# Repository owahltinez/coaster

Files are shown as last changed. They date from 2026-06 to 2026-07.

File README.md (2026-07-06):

# Coaster

Very simple battery-operated device. When you push a button, the light turns on for a few seconds
and then it turns off. It is designed to be used as a coaster such that, when gently pushing a glass
down on the device, the light activates making the contents of the glass glow.

Pressing down on the coaster triggers a ~8 second light show: the LEDs ramp up to full
brightness, "breathe" gently five times, and fade back to black. Between shows the device
sleeps at ~1 µA — there is no on/off switch and none is needed.

## Repository layout

- `firmware/` — AVR C firmware and its build/flash Makefile.
- `pcb/` — v0.3 board design (KiCad, generated from python scripts) and footprints.
- `enclosure/` — 3D-printed shell (FreeCAD source + STEP/STL export).
- `tools/` — pinned toolchain containers (KiCad for the board, avr-gcc for the firmware).

All subdirectories share the same verbs, and the top-level Makefile forwards to each:
`make build` (firmware hex + board + enclosure exports), `make test` (flash-fit check +
board DRC + enclosure solidity check), `make clean`. Domain-specific verbs forward to the
relevant subdirectory: `make flash` / `make fuses` (firmware programming),
`make review` (board render / PDF / STEP), `make fab` (JLCPCB order bundle). The
firmware and PCB verbs run inside pinned containers — `make image` builds them once
(see Software); flashing stays on the host.

## How it works

The button connects an MCU pin (with its internal pull-up) to ground. Pressing it fires a
falling-edge interrupt on one of the ATtiny202's fully-asynchronous pins, which wakes the
chip from power-down sleep with the main clock stopped — a press costs effectively no
charge. The firmware debounces the edge, plays the show over hardware PWM through a
MOSFET driving four series-resistored LEDs, and goes back to sleep.

Two details carry hard-won lessons from v0.2:

- The show also plays once when the battery is inserted (a power-on reset doubles as a
  built-in self test), but *only* on a power-on reset: a brown-out reset means a dying
  cell sagged below 1.8V mid-show, and playing again would loop the cell to death — so a
  brown-out goes straight back to sleep and the coaster simply dims gracefully as the
  battery wears out.
- Wake edges that turn out not to be presses (e.g. contact bounce while lifting a glass
  off a held-down button) are filtered by a 20ms debounce check, so the show plays on
  deliberate presses only.

## Hardware

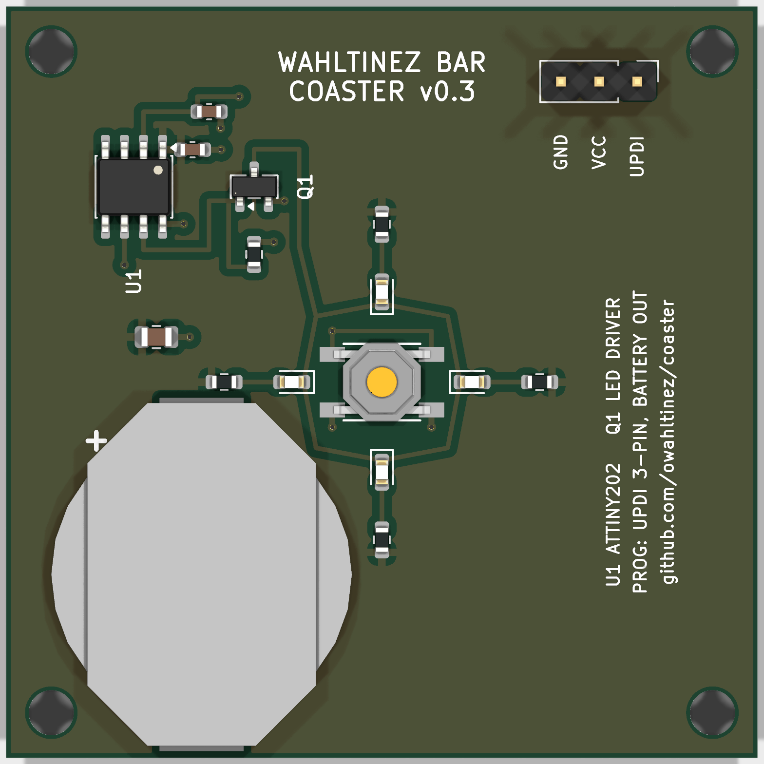
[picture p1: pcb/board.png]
coaster v0.3 board


The v0.3 design (KiCad) lives in `pcb/`:

- `pcb/design.py` is the circuit as data — parts, placements, and the netlist defined
  once. This is the file to read or edit; it is the source of truth.
- `pcb/DESIGN.md` is the design specification: pin map, BOM with part rationale,
  ordering plan, and the validation checklists.
- `pcb/generate.py` turns `design.py` into `coaster.kicad_pcb` (committed for
  convenience). `make build` regenerates the board and validates connectivity; `make
  test` runs DRC; `make review` produces a board render, a 1:1 printable PDF, and a STEP
  model for CAD fit checks.
- `pcb/coaster.pretty/` — project footprints with pad geometry extracted from the
  manufactured v0.2 board (battery holder, tactile switch).

There is no schematic: JLCPCB takes Gerbers + BOM + CPL (not a schematic), the board is
built and checked directly against `design.py`, and `design.py` itself documents the
circuit — so a derived schematic would add nothing.

The previous revision (v0.2: ATtiny13A, EasyEDA, CR2032) is archived at release
[v0.2.1](https://github.com/owahltinez/coaster/releases/tag/v0.2.1), including its
firmware, schematic renderings, and 3D printing assets.

### Production

All SMD parts are LCSC-stocked, so the board can be fabricated and assembled through
JLCPCB — the only hand-assembly per unit is dropping a CR2016 into the holder. `make
fab` writes the three JLCPCB uploads (Gerbers zip + BOM + CPL) to `pcb/dist/`; order
with **white soldermask** (the board face is the reflector behind the LEDs). The full
step-by-step — orientation checks, stock confirmation, post-assembly flashing — is the
ordering plan in [pcb/DESIGN.md](pcb/DESIGN.md).

Rough per-unit estimates as of June 2026 (USD, assembled and shipped; ~A$1.55/US$):

| Per unit | Qty 30  | Qty 100 | Qty 1k  | Qty 10k |
|---|---|---|---|---|
| Parts | $0.74 | $0.70 | ~$0.60  | ~$0.47  |
| Feeder/setup/stencil | $0.72 | $0.30 | ~$0.04  | ~$0 |
| PCB + assembly | $0.47 | $0.40 | ~$0.30  | ~$0.20  |
| Board shipping | $0.20 | $0.35 | ~$0.10  | ~$0.05  |
| CR2016 (name-brand) | $0.65 | $0.35 | ~$0.20  | ~$0.12  |
| Enclosure | $0.60 (FDM) | $0.60 (FDM) | ~$1.00 (print farm)\* | ~$0.30 (molded)\* |
| **Finished coaster** | **~$3.40** | **~$2.70** | **~$2.25** | **~$1.10** |

\*The 1k column keeps FDM but prices it honestly: ~2,500 printer-hours, which a small
farm of four budget printers clears in under a month — filament plus printer
amortization lands near $1/unit, with no tooling commitment and the printers kept at
the end. The 10k column switches to injection molding (aluminum tooling, amortized);
that is also the column where a further redesign pays — shrinking the PCB from the
structural 50×50mm to a ~25mm puck and letting the molded shell carry the mechanical
roles would cut the PCB line by ~$0.10 more. If 1k is a milestone toward 10k rather
than the destination, rapid aluminum tooling (~$1–1.5k) prices similarly at 1k and
carries forward.

The electronics architecture is the same in every column — the MCU ($0.30–0.43) is the
cheapest line that matters, and it is the entire personality of the product. Prices
drift; get a real quote from the [JLCPCB quote tool](https://jlcpcb.com/quote) and
confirm ATtiny202 stock at order time (the ATtiny402 is a firmware-compatible drop-in
substitute).

## Software

The firmware and board builds run in **pinned containers** (`tools/`), so the host
needs neither a KiCad nor an AVR toolchain — only a container engine. Pinning is what
keeps the artifacts reproducible: the committed board is KiCad-10 format and host KiCad
drifts (Debian ships v9, which can't even open a v10 board), and the ATtiny202 firmware
needs avr-gcc ≥ 12 (the README used to hand-source `avr-gcc@14` from the
[osx-cross/avr](https://github.com/osx-cross/homebrew-avr) tap on macOS). Build the
images once, then the verbs route through them automatically:

```bash
make image               # build both images: coaster-fw + coaster-pcb (re-run after editing a Containerfile)
make build               # firmware hex + board + enclosure, each in its toolchain
make fab                 # regenerate the board + emit the JLCPCB bundle, in the container
```

The enclosure builds the same way, in a pinned FreeCAD 1.1.1 container (`make image`
builds it too) — so the host needs no FreeCAD either, and the old macOS `freecadcmd`
symlink dance is gone.

`docker` here is a [Podman](https://podman.io) alias (`podman-docker`); override
`CONTAINER_ENGINE` to use another runtime. Rootless Podman maps container-root to your
UID (the Makefile passes `--user 0`), so generated files come back owned by you. The
rule is **produce artifacts in a container, touch hardware on the host** — so flashing
(`make flash` / `make fuses`, which need a USB-serial adapter) stays on the host and
needs `avrdude` (≥ 7, for `serialupdi`) installed there; see Flashing below.

The **enclosure** build still runs on the host via FreeCAD (`freecadcmd`); on macOS the
app bundle doesn't expose its CLI, so symlink it once:

```bash
ln -s /Applications/FreeCAD.app/Contents/Resources/bin/freecadcmd /opt/homebrew/bin/freecadcmd
```

### Flashing

No dedicated programmer needed: UPDI works over any USB-serial adapter with a single
~1kΩ resistor bridging the adapter's TX to RX, and RX wired to the board's UPDI pad
(plus VDD and GND — the J1 pads are labeled on the silkscreen).

```bash
make flash   # writes main.hex over serialupdi
make fuses   # once per chip: brown-out detector at 1.8V, sampled in sleep
```

The fuses matter: the factory default leaves the BOD disabled, which allows undefined
behavior when the battery sags, and the firmware's brown-out logic depends on it.

For flashing a stack of boards hands-free, `make flash-loop` runs a continuous loop:
plug a board onto the jig, it flashes + fuses + verifies automatically, then waits for
you to remove it before arming the next. **The board reports its own result** — a good
flash plays a distinct rapid blink and a failed one stays dark, so you never look at the
screen. The blink is gated on a one-shot EEPROM flag the loop writes only after both
flash and fuses verify (a single avrdude run, which aborts before the arm step on any
earlier failure); the firmware blinks once on the next boot and clears the flag, so it
fires exactly once per flash and never again in the field.

Gotchas:

- **Remove the coin cell before flashing.** The adapter drives VDD and would back-feed
  the (non-rechargeable) lithium cell.
- That's it. The v0.2 list of ISP gotchas (LEDs clamping MOSI, flaky readback, wedged
  programmers) died with the ISP header: UPDI shares no pins with anything else on this
  board, by construction.

## Power estimates

Assumptions: CR2016 rated at 75 mAh (~70 mAh usable), ~8 mA LED draw at 100% duty on a
fresh cell, ~1 µA sleep current (BOD sampled).

| Event | Cost | Notes |
|---|---|---|
| Light show (~8 s) | ~15 µAh  | avg ~60% LED duty + ~1.5 mA MCU active |
| Button press | ~0 | pin-change wake; nothing touches the supply |
| Standby (per day) | ~26 µAh  | ~1 µA sleep + battery self-discharge |

Expected battery life:

| Usage pattern | Battery life |
|---|---|
| Never pressed (shelf) | ~7 years |
| ~5 presses/day | ~2 years |
| ~30 presses/day (bar duty)  | ~5 months |
| Theoretical max shows | ~4,500 |

The punchline: v0.3 runs on a cell with a third of the v0.2 battery's capacity and
still matches its life, because presses are now free (each v0.2 press dead-shorted the
battery and cost as much as a show) and sleep current dropped ~4×.

## Demo

> TODO: Add demo pictures / video.

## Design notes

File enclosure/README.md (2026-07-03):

# Enclosure

3D-printed shell for the coaster. The top is a solid "donut-piston": a
continuous disc that holds the static weight of a glass but deflects as a whole
— piston-style, carried on a ring of snap arms — to click the tactile button at
the center of the PCB. (The v0.2 lid was a spiral flexure; v0.3 replaced it with
this solid piston.)

`coaster.FCStd` (FreeCAD) is the CAD source of truth. It contains two bodies,
each exported as its own print/CAD artifact:

| Body | Size (mm)  | What it is |
|---|---|---|
| Top | Ø90 x 5.4  | Solid donut-piston lid: skin + central press post + 6 snap arms |
| Bottom | Ø90 x 6.5  | Base tray holding the PCB |

Assembled height is **8.1 mm** (the lid nests into the tray). The tray wall is
the single height knob (`VarSet.BottomHeight`): the lid sits on the wall rim and
its placement, the snap-pocket depth, and the rim ceiling all track it, so
changing `BottomHeight` moves the whole interlock rigidly. The one feature that
does *not* track is the central `Press Post` (it grows down from the lid skin);
its length must change by the same amount in the opposite sense to keep the post
tip on the button — at `BottomHeight` 6.5 the post is 3.5 mm. (v0.3.0 shipped at
`BottomHeight` 7.5 / 9.1 mm tall; the tray was thinned 1.0 mm after the CR2016
holder replaced the CR2032.)

The tray floor under the board (the `PCB Recess` pocket floor) is **0.6 mm** — three full
print layers. It was 0.5 mm, an awkward 2.5 layers that printed thin and dimpled a little when
the board was pressed onto the pegs. The board sits flat *on* this floor, so it can't be
thickened much without cost: more material either raises the board into the tight lid/holder
clearance or makes the coaster taller (the underside is flat on the table — no dead space). So
the fix is minimal: make `PCB Recess` 0.1 mm shallower (1.5 → 1.4 mm), raising the whole indent
floor uniformly to 0.6 mm. The board seat rises 0.1 mm (negligible for post travel) and overall
height is unchanged.

**This 1.0 mm is on probation — confirm it on a printed article before a batch.**
The constraint is not static fit but press deflection: the donut-piston deflects
~0.6 mm down at the battery-holder radius under a heavy glass press, and at a
6.5 mm tray it has only ~0.25 mm of static clearance over the holder there. So
the lid is expected to *graze* the holder under the heaviest glasses — which
stiffens the press rather than blocking the click (the holder adds a support, it
does not lock the centre post). An axisymmetric sim can't settle how much this
changes the feel; print one tray, drop in a populated board, and press a real
glass. If the press feels notably stiffer or the holder shows witness marks,
back `BottomHeight` off toward 7.0 (each 0.1 mm buys ~0.1 mm of clearance).

## Building

The build runs in a pinned FreeCAD 1.1.1 container (`tools/Containerfile.cad`), so the
host needs no FreeCAD — `make image` (from the repo root) builds it once. The source is
authored in FreeCAD 1.1; stable 1.0.0 breaks the sketch/Origin attachment, so the
version is pinned to match. Same verbs as the other subdirectories (run from the repo
root so they route through the container, or `make -C enclosure …` inside it):

```bash
make build   # validate + export coaster-{top,bottom}.{step,stl}
make test    # validate only: full recompute, every body a valid closed solid
make clean
```

The STL files are the 3D printing assets; the STEP files are for CAD
interference checks against the board (`make -C ../pcb review` exports the
matching `coaster.step` board model).

Material use (solid volume from the model × 1.24 g/cm³ PLA; the bodies are
thin-walled, so a real print lands close): Top 8.3 cm³ (~10 g), Bottom 11.4 cm³
(~14 g) — about 24 g and ~$0.50 of filament per coaster. Re-slice to confirm.

## Liquid strategy

The coaster lives under sweating glasses. The v0.2 lid was a spiral flexure whose cuts
were an open path into the shell, plugged by a separate clear-PETG shield membrane. The
v0.3 donut-piston removes the problem instead of patching it: the top is a **continuous
solid skin with no through-cuts**, so drips and condensation that reach it shed outward and
never find a path to the electronics, the bare battery contact, or the switch. The lid is
its own barrier — which is why v0.3 has no Shield body.

**Anti-stick — flat v0.3, radial ridges in v0.3.1.** A bare smooth skin has a second liquid
problem: a sweat film between a glass base and the flat top is a capillary bond — order ~N of
pull, against the coaster's own ~0.24 N weight — that lifts the whole lightweight coaster when
the glass is raised. **v0.3** ships the plain flat lid (`coaster-v0.3.FCStd`); the anti-stick
texture is **v0.3.1** (`coaster.FCStd`, the live source).

A shallow *recessed field* between raised dots (an earlier printed attempt) makes it **worse**:
sweat floods the 0.4 mm field, bridges into one continuous film, and the whole thing becomes a
suction cup. The lesson from that print: the fix is **drainage**, not contact-area reduction.
v0.3.1 cuts **12 radial channels** (2.0 mm wide × 0.8 mm deep) running from r≈13 to r≈42. They
*drain* sweat off toward the edge and give air a straight path in the instant the glass lifts —
no standing film to seal. (A first print with 24 thin 1.0 × 0.4 mm lines was wrong: the lines
were too small to feel and fused, and running them to the very rim printed jagged. Fewer, much
wider and deeper channels that stop ~3 mm short of the edge print cleanly and are actually
felt.) The channel walls are **tapered ~40°** from vertical (`TaperAngle` on the pocket) — wide
at the glass face, narrowing to a ~0.8 mm floor. Since the Top prints face-down, the channel is
a recess in the bed-side surface; a square `]` profile would leave a flat, down-facing floor
that bridges and prints rough, whereas the taper makes the walls self-supporting overhangs and
shrinks that bridge. (A self-supporting *full* V — no flat floor — needs width ≤ 2× depth, i.e.
~1.6 mm at this 0.8 mm depth; 2.0 mm/40° is the chosen middle ground between width and a small
floor.) It also drains better — no square corners to trap water. Radial (not a grid or field)
also prints well: the rim between channels stays flat, and the flat r42–45 band gives the
face-down print a clean, continuous first-layer perimeter.

The channels are **blind**: floors leave ≥ 0.8 mm of skin in the disc, so the waterproof barrier
holds; plateaus between them are full thickness. The channel depth is **uniform 0.8 mm the whole
way** — including across the 0.4 mm outer flexure hinge, where a full-depth groove would otherwise
breach. Rather than shallowing the groove there (which left an ugly depth step), the fix adds
material on the *underside* directly beneath each channel at the hinge: **12 discrete backing bars**
(3.5 mm wide × 1.2 mm) so 0.4 mm of skin remains under the 0.8 mm groove. Because the channels are
radial, the bars don't island the thin membrane, and the hinge still flexes *between* them, so the
click stays near the flat lid's (the bars are non-axisymmetric, so `sim/` slices between them and
can't score their small stiffening; see `meridian_polygon`). The inner hinge and the central
button/LED zone are left ungrooved. Earlier forms — a spider-web, a square grid, a bump field —
were busier, off-centre on the round face, or (the bump field) actively worse in a print; simple
uniform-depth radial drainage channels are the result.

## Press mechanics

The donut-piston's click force and travel are simulated in `sim/` — an axisymmetric FEA
of the Top sliced straight from this `coaster.FCStd` and calibrated to a measured press.
See `sim/README.md`.

## Snap arms (known weak point)

The six cantilever arms latch the lid into the tray pockets, and they are the enclosure's
fragility hotspot. The flexing beam is short (~1.5 mm), so even the ~0.25 mm it deflects
to clear the wall lip on insertion is a high bending strain at the root — the arms crack
there. Levers, in order of effect:

- **Beam thickness** (`Sketch004` datum 16, the radial dimension) — set to **1.6 mm**, the
  thickest the root fillets allow with the hook at mid-beam (1.8 mm+ makes the fillets fail
  to resolve). Two effects trade off: thicker prints more robustly with better layer bonding
  (a thin ~1.0 mm arm prints as a fragile near-single-wall column), but thicker also raises
  the bending strain on the ~0.25 mm snap-over. Which dominates is a print-test question.
  That thick + fillet fight for room at the root is the argument for eventually moving the
  hook to the tip — it frees the root for a thick, well-filleted, long-flexing beam.
- **Material** — print in **PETG** (ductile; the press sim assumes it). PLA snaps.
- **Orientation** — the arms bend radially, so on a flat-printed lid the layer lines run
  *across* the bending plane and the root fails by delamination regardless of strain. There
  is no single orientation that favours all six radial arms; print with extra perimeters so
  the beam is near-solid, and treat orientation as a likely co-cause if cracking persists.
- **Root fillets** — outer (tension-side) and inner both 0.8 mm; relieve the stress
  concentration only, not the bulk strain.

If thinning + PETG + perimeters still isn't enough, the cantilever is at the limit of what
this footprint allows and the retention method itself should be reconsidered.

Lateral fit between lid and tray is set entirely by the arms in their pockets — the lid
just rests on the wall rim, there is no separate register. The tangential fit is
`Pocket002.Length` minus the arm width `Pad003.Length` (4.0 mm), and it is a per-printer
tuning knob: the model is line-to-line radially and the pocket runs 0.1 mm wider than the
arm tangentially (`Pocket002.Length` = 4.1), so most felt play is print tolerance opening
the fit. Tighten `Pocket002.Length` toward 4.0 if the lid wobbles; loosen it if the lid
binds going on.

## Design constraints (50 x 50 mm board)

- Board outline: 50 x 50 mm, 3 mm mounting holes in all four corners at
  (3, 3), (3, 47), (47, 3), (47, 47).
- The piston must press the button at the board center.
- Center clearance: the LED ring sits 6 mm from center; the central press post
  must stay narrow enough not to cover the LEDs.
- The UPDI programming header (J1, near a board-edge corner) must stay reachable,
  or accept opening the shell to reflash.

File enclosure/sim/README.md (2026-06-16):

# Press-mechanics simulation

Predicts the coaster's **click force** — how hard you must press, and where, to
actuate the center switch — directly from the CAD. Run it after changing the
Top to check the press feel before committing a print.

```bash
make sim                 # from the repo root: runs in the pinned container
make -C enclosure sim     # on the host (needs FreeCAD with bundled gmsh + ccx)
```

Outputs (regenerated each run, git-ignored): `results.md` (the report) and
`curve.svg` (the headline plot — click force vs. load radius).

---

## The method (reusable for any solid-of-revolution part)

This harness is a worked example of a general technique: **calibrated
axisymmetric FEA driven straight off the CAD solid.** The ideas below transfer
to any revolved mechanism (a snap dome, a diaphragm, a Belleville spring, a
press-fit boss).

### 1. Slice the real solid — don't reconstruct it

The Top is a solid of revolution, so its press mechanics reduce *exactly* to a
2D axisymmetric problem. Instead of re-authoring the shape as code (which then
drifts from the CAD), `model.meridian_polygon` **cuts the real FreeCAD solid**
through an arm-free axial plane and returns the `(r, z)` meridian outline. Gmsh
meshes that polygon into quadratic axisymmetric triangles (CAX6); CalculiX
solves a linear static load. Because the mesh *is* the sliced section, the
simulation can never disagree with the model — change the donut, the hinge, the
post, re-run, and the section follows. It also handles whatever the shape
becomes (corrugations, fillets) with no code change.

The snap arms break strict axisymmetry but carry no press load, so the slicer
sweeps azimuths to find a plane that misses them.

### 2. Why 2D, not the "real" 3D solid

A full 3D solve of the *actual* solid is the obvious thing to want, and it's the
wrong tool here. The press response is dominated by bending of the 0.4 mm
membrane/hinge, which needs ~3 elements through its thickness. In a 2D
axisymmetric slice that is free (~10k elements, sub-second). In 3D it forces
~0.13 mm elements across a 90 mm disk — millions of tetrahedra, minutes to mesh,
many minutes to hours to solve, and finicky to even mesh cleanly (we measured
this). Axisymmetry is the correct, cheap, *more accurate* tool for a revolved
part. 3D only earns its cost for genuinely non-axisymmetric questions (e.g. how
much an off-center glass *tilts*), which this design doesn't hinge on.

### 3. Calibrate the scale from one measured press

The model is linear, so the absolute modulus only sets an overall compliance
scale — it cancels. We fix that scale with **one measured click force**: press
the printed part at a known spot, read the grams at the click (`CALIBRATION`).
Everything else then follows from FE compliance *ratios*, which need no
material constant. (`E_MPA`, `MESH_SIZE` are solver settings, not design data.)

### 4. Validate with a second press at a different radius

With two measured presses at different radii, the model must reproduce their
**click-force ratio from geometry alone** — a real falsifiable check, not a fit.
Here the center press (330 g) and a two-finger press on the donut (1400 g) give
a 4.24× ratio; the model predicts it within ~10% and the two presses agree on
the absolute scale to ~10%. The residual is the center press's sensitivity to
how a fingertip's pressure distributes; the two-finger press (a clean ring) is
the robust scale anchor.

### 5. The output is a curve, because contact location is everything

A glass is a tube: the press force runs **down its walls** and enters the base
as a *ring at the wall radius* — not spread over the base, not at the base rim.
So the meaningful input is the **load radius**, and the output is a click-force-
vs-load-radius curve (`curve.svg`). To predict a glass, read the curve at its
load radius:

- **Recessed base** → loads on its recess ring (clean; the model nails it).
- **Flat base** → loads a few mm *inboard* of its contact edge (the surface
  dishes away from the rim under load), so use ~edge radius minus a few mm.

### 6. Don't model the presser — and know the limits

Modeling the glass as a body (contact analysis) was tried and isn't worth it:
its entire effect reduces to "a ring at the load radius," while a contact solve
adds fragile unilateral-contact nonlinearity and per-glass geometry — and it
would *not* remove the residual uncertainty, because that's set by sub-mm base
flatness. Honest accuracy budget: **point/finger presses and the curve *shape*
are reliable; flat-glass absolute force carries ~±1 kg** from contact detail.
That's fine for "comfortable and won't self-trigger," not a precision number.

---

## Files

- `model.py` — the model as data + functions: the calibration presses and
  validation glasses (the only inputs the CAD lacks), and the slice → mesh →
  solve → parse machinery. Geometry is read from the FCStd, never typed here.
- `run.py` — orchestration: slice + mesh once, solve the presses (scale +
  validation) and the radius sweep, write `results.md` and `curve.svg`.
- `gmsh` and `ccx` ship inside the pinned FreeCAD container, so `make sim`
  needs no extra tools; `model.locate` also finds them in a host FreeCAD.

## Reusing this on another part

1. Point `model.DESIGN_FILE` at the new FCStd; make sure the bodies/sketches the
   model reads by label (`Wall Profile` for the seat radius, etc.) exist or
   adjust `read_design`.
2. Print it, measure one click force to set `CALIBRATION`, and ideally a second
   at a different radius to validate.
3. `make sim`.

## Note on the design file

This models `enclosure/coaster.FCStd` — the donut-piston Top that `export.py`
builds and the canonical enclosure for v0.3. (The v0.2 spiral flexure it
replaced lives at tag v0.2.1.)

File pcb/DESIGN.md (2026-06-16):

# Coaster v0.3 — Design Specification

The circuit itself lives in `design.py` (the single source of truth); this document
records the design intent: how the MCU is wired, why each part is what it is, and what
to verify before committing to a batch. The previous revision (v0.2: ATtiny13A,
EasyEDA) is archived at release v0.2.1; every choice below traces to a lesson learned
debugging it.

## Design rationale

- **MCU: ATtiny202** — in production, real brown-out detector, UPDI single-wire
  programming, ~1µA power-down sleep. 2KB flash / 128B SRAM is 7× the current
  firmware; the ATtiny402 (4KB/256B) is a drop-in substitute at +$0.22 if the
  firmware ever outgrows it — a binary built for the 202 runs unmodified on a 402.
- **Button on a GPIO with pin-interrupt wake** — presses cost ~0 µAh and richer UX
  (double-tap, long-press) becomes possible. v0.2 woke by dead-shorting the battery,
  which cost ~11 µAh per press and destroyed SRAM state.
- **One series resistor per LED + low-side MOSFET driver** — LED current set by
  design, not by battery internal resistance and pin-driver luck.
- **Real decoupling (C1) and bulk (C2) capacitance** — transient immunity; rides
  through battery-holder micro-dropouts.
- **3-pad UPDI header** — programming cannot collide with the LEDs by construction
  (v0.2's ISP shared the LED pin, which made flashing finicky).

## MCU pin map (ATtiny202, SOIC-8)

| Pin | Port | Net | Function |
|-----|---|---|---|
| 1 | VDD  | VCC | Power |
| 2 | PA6  | BUTTON | Button input, internal pull-up, falling-edge wake. PA6 chosen deliberately: Px2/Px6 are the fully-asynchronous pins that can edge-wake from power-down |
| 3 | PA7  | — | Unused (firmware enables pull-up) |
| 4 | PA1  | — | Unused / spare test pad (optional) |
| 5 | PA2  | — | Unused / spare test pad (optional) |
| 6 | PA0  | UPDI | Programming only — route to header, leave in UPDI mode (do NOT fuse to GPIO/RESET) |
| 7 | PA3  | LED_PWM  | TCA0 WO0 hardware PWM → MOSFET gate |
| 8 | GND  | GND | Ground |

## Connections (net by net)

```
VCC:      BT1+, U1-1, C1-1, C2-1, R1-1, R2-1, R3-1, R4-1, J1-2 (UPDI header VDD)
GND:      BT1-, U1-8, C1-2, C2-2, Q1-source, SW1-(2nd terminal), C3-2, R5-2, J1-3
LED_PWM:  U1-7 (PA3), Q1-gate, R5-1 (100k pulldown to GND)
LED_K:    Q1-drain, L1-cathode, L2-cathode, L3-cathode, L4-cathode
LED legs: VCC → R{1..4} (100Ω) → L{1..4} anode ; all cathodes → LED_K
BUTTON:   U1-2 (PA6), SW1-(1st terminal), C3-1 (100nF debounce, optional)
UPDI:     U1-6 (PA0), J1-1
```

Notes:

- R5 (gate pulldown) keeps the LEDs off while PA3 floats during programming/reset.
- C1 must sit physically adjacent to U1 pins 1/8; C2 anywhere near the battery holder.
- 100Ω per LED ≈ 3–5mA per LED fresh (3.2V → Vf 2.7V across 100Ω), tapering toward ~0
  as the cell sags to Vf; total LED load ~12–20mA fresh. Through the MOSFET, the MCU pin
  only drives gate charge. (The resistor is more ballast than limiter at this headroom —
  matches the four parallel LEDs; first-article measurement sets the final value.)
- J1: 1×3 through-hole pads, 2.54mm pitch, near the board edge: [UPDI | VDD | GND].
  Through-hole so a header can be pressed in at an angle or soldered for batch work.

## BOM (with JLCPCB catalog tier)

| Ref | Part | Package | LCSC # | Tier | ~Unit USD |
|-----|---|---|---|---|---|
| U1 | ATtiny202-SSN | SOIC-8 | C2052951 (-SSNR) | Extended | 0.43 |
| Q1 | AO3400A N-MOSFET | SOT-23 | C20917 | Basic | 0.01 |
| L1–L4 | White LED KT-0603W | 0603 | C2290 | Basic | 0.003 |
| R1–R4 | 100Ω 1% | 0603 | C22775 | Basic | 0.001 |
| R5 | 100kΩ 1% | 0603 | C25803 | Basic | 0.001 |
| C1 | 100nF X7R 50V | 0603 | C14663 | Basic | 0.001 |
| C2 | 22µF X5R 25V | 0805 | C45783 | Basic | 0.01 |
| C3 | 100nF (debounce, optional) | 0603 | C14663 | Basic | 0.001 |
| SW1 | Tactile switch TS-1187A-B-A-B | SMD | C318884 | Extended | 0.02 |
| BT1 | CR2016 holder MY-2016-02 | SMD | C2979176 | Extended | 0.16 |

These LCSC numbers are the source of truth in `design.py`'s `LCSC` map, from
which `make fab` emits the BOM — the table here is documentation. The five
non-jellybean parts are deliberate (see below); the passives are pinned to
in-stock JLCPCB *Basic* SKUs (no feeder fee), substitutable by any same
value/package/tolerance Basic part if one lapses. Per-board parts ≈ $0.74 USD. Extended parts (U1, SW1, BT1) cost a $3 feeder fee
each per order — $0.30/board at qty 30. Option: leave BT1 off the assembly and
hand-solder it (two large pads) to save its fee.

Part choices worth defending:

- **Q1 must be a logic-level FET.** The AO3400A (Vgs(th) 0.65–1.45V) is fully enhanced
  at worn-cell voltage; a 2N7002 (Vgs(th) up to 2.5V worst-case) would be driven barely
  above threshold for most of the cell's life and read as dim/flickering LEDs.
- **L1–L4: efficiency at coin-cell current, not headline mcd.** Every white LED is
  ~2.7–3.4V Vf (blue die + phosphor), and a CR2016 offers only ~0.3V above Vf — so the
  LEDs run at a few mA, never their 20mA rating, and the figure that matters is light
  per mA at low current, not mcd@20mA. The KT-0603W (Basic, C2290) gives 360mcd @ 5mA
  (~72 mcd/mA) versus the XL-1608UWC-04's 130mcd @ 20mA (~6.5 mcd/mA): ~11× the light at
  the current this circuit actually delivers — and it's a Basic part, so no feeder fee.
  The glow is the entire point of the device; this is where it's bought. (An earlier
  revision had this backwards and paid a feeder fee for the dimmer part — see git log.)
- **SW1 is mechanically load-bearing.** The enclosure flexure is dimensioned around
  this switch's body height and actuation force, and its footprint is the one extracted
  from the manufactured v0.2 board. A basic-catalog switch would save $0.10/board and
  risk re-validating the press feel.
- **BT1 takes a CR2016, not a CR2032.** Same Ø20mm cell, but the MY-2016-02 holder is
  2.2mm tall versus 3.6mm, slimming the enclosure (the holder was the tallest
  component). ~75mAh still gives 2+ years at a few presses a day — µA sleep dominates
  and presses are now ~free.

## Ordering plan

30 boards, JLCPCB Economic assembly (30 is the Economic cap — the per-unit sweet spot).
Estimated ~$100–105 AUD shipped (economy mail).

`make fab` generates the three JLCPCB uploads into `pcb/dist/` (gitignored) from the
board geometry and `design.py`'s part data: `coaster-gerbers.zip` (Gerbers + drill),
`coaster-bom.csv`, and `coaster-cpl.csv` (pick-and-place). The UPDI header (J1,
through-hole) and the mounting holes are excluded from assembly — J1 is pressed/soldered
by hand for batch flashing. Then at the JLCPCB quote tool:

1. Upload `coaster-gerbers.zip`; set **white soldermask** (same price): the board face
   is the reflector behind the LEDs — dark mask absorbs a large fraction of the show's
   light for free.
2. Quantity 30, SMT assembly on the top side; upload `coaster-bom.csv` and
   `coaster-cpl.csv`.
3. Confirm **ATtiny202 (C2052951)** stock/tier at order time; if out of stock, the
   ATtiny402 is a drop-in substitute (same firmware binary), or order assembly without U1
   and hand-solder the SOIC-8s.
4. On the assembly preview, **verify part orientations**. The KiCad and JLCPCB rotation
   conventions differ for some packages, and `ROTATION_CORRECTION` in `design.py` is empty
   until a real preview is checked. The one that bites: BT1's pads are symmetric but the
   part is not — the insertion mouth must face the **west** board edge (cell slides in/out
   over bare board). Record any rotation fix in `ROTATION_CORRECTION` (keyed by footprint)
   and re-run `make fab`, so the next order is right by construction.

Boards arrive **blank**: program each over the UPDI header (`make fuses` once to set the
1.8V BOD, then `make flash`) and drop in a CR2016 — the cells are not part of the JLCPCB
order. Validate one unit against the first-article checklist below before committing the
batch to enclosures and cells.

## Firmware port checklist (ATtiny13A → ATtiny202)

- [x] PWM: TCA0 in single-slope PWM, WO0 on PA3 (default PORTMUX routing); duty updates
      via CMP0BUF; bright phase at full duty now that R1–R4 set the current
- [x] Button: PA6 input, internal pull-up (PORTA.PIN6CTRL), falling-edge interrupt, wake from power-down
- [x] Sleep: SLPCTRL power-down; expected sleep current ~0.1–2µA (BOD in sampled mode)
- [x] BOD: configured via FUSE.BODCFG at programming time (`make fuses`, 0x06) — enabled
      at 1.8V, sampled mode in sleep
- [x] Debounce in firmware (20ms, also filters release-bounce edges); C3 is belt-and-suspenders
- [x] Show logic carries over: ramp, breathe ×5 ending on the dim phase, squared perceptual
      fade (~8s total; the v0.2 battery-recovery settle phase is gone — presses no longer
      touch the supply rail)
- [x] Reset logic: show on `PORF` only (battery insertion = self-test); a brown-out reset
      skips to sleep so a dying cell cannot reset-relight; button wakes are not resets at all
- [x] Programming: avrdude serialupdi (any USB-serial adapter + 1 resistor), `make flash`

Builds at 422 / 2048 bytes with avr-gcc 14. Hardware verification of all of the above
lives in the first-article checklist below.

## First-article validation (before deploying all 30)

- [ ] Programming via UPDI header works
- [ ] Sleep current measured < 5µA
- [ ] Show plays on button press; press costs no measurable charge
- [ ] Brightness through an actual glass: 100Ω is a starting value, not a decision —
      if too dim, rework toward 68Ω and re-measure worn-battery behavior; if it drains
      too fast, back off toward 150Ω
- [ ] LED polarity on the assembly preview: cathode (pad 1) faces the board center
      (LED_K). The KT-0603W is a new part vs the preview-checked rc1 LED — confirm its
      orientation; if reversed, add the LED footprint to ROTATION_CORRECTION (+180) and
      re-run `make fab` (CPL only; gerbers unchanged)
- [ ] Worn-battery test: show degrades gracefully (dims) with no reset loop
- [ ] Bench-supply + series-resistor test (30–50Ω) simulating a dying cell
- [ ] Press during show, long-press, rapid double-press behave sanely
- [ ] Splash test: assembled unit, dribble water over the top — the solid piston lid
      sheds it, nothing reaches the PCB, battery contact stays dry, button still clicks

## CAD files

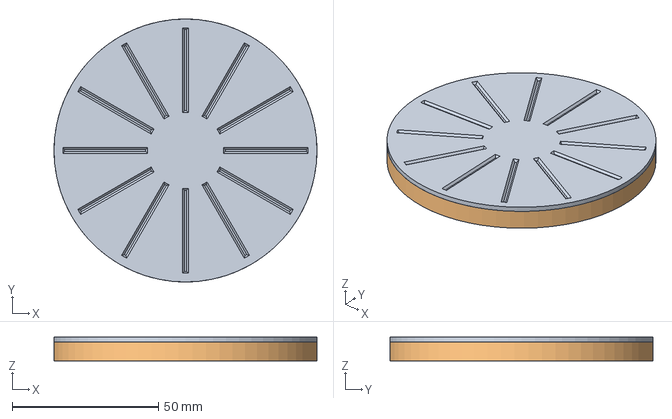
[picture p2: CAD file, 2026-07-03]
enclosure/coaster.FCStd
90.0 x 90.0 x 8.10 mm
Top
Bottom

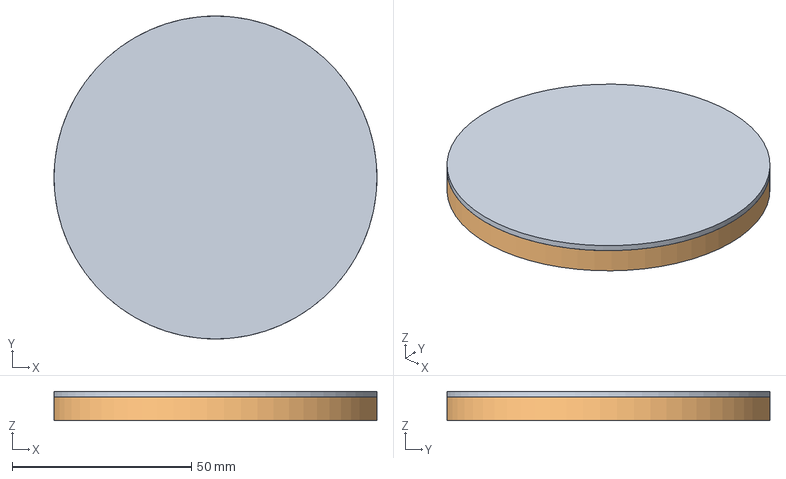
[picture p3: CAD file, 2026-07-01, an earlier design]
enclosure/coaster-v0.3.FCStd
90.0 x 90.0 x 8.10 mm
Top
Bottom

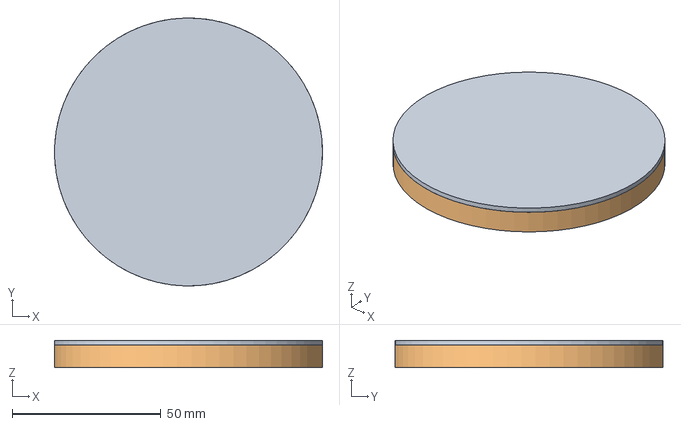
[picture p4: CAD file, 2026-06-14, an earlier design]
enclosure/coaster-v0.2.2.FCStd
90.0 x 90.0 x 9.10 mm
Top
Bottom

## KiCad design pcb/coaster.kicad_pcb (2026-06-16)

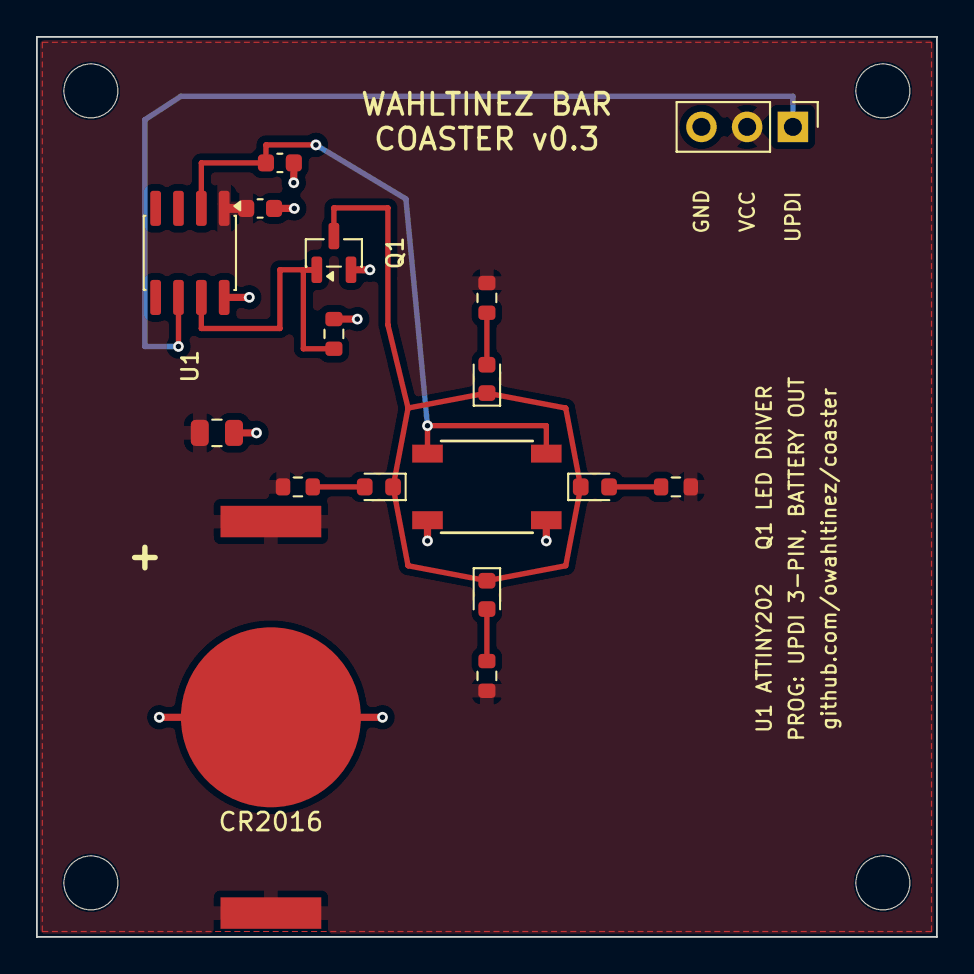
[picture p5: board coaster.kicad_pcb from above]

Board: 2 copper layers, 50.0 x 50.0 mm, 21 parts (0 on the bottom side), 10 nets.

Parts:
BT1: CR2016; MY-2016-02
C1, C3: 100nF; C_0603_1608Metric
C2: 22uF; C_0805_2012Metric
H1, H2, H3, H4: 3mm; MountingHole_3mm
J1: UPDI; PinHeader_1x03_P2.54mm_Vertical
L1, L2, L3, L4: KT-0603W; LED_0603_1608Metric
Q1: AO3400A; SOT-23
R1, R2, R3, R4: 100; R_0603_1608Metric
R5: 100k; R_0603_1608Metric
SW1: TS-1187A-B-A-B; TS-1187A
U1: ATtiny202-SSN; SOIC-8_3.9x4.9mm_P1.27mm

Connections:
BUTTON: C3.1, SW1.1, U1.2
GND: BT1.2, C1.2, C2.2, C3.2, J1.3, Q1.2, R5.2, SW1.2, U1.8
LED_A1: L1.2, R1.2
LED_A2: L2.2, R2.2
LED_A3: L3.2, R3.2
LED_A4: L4.2, R4.2
LED_K: L1.1, L2.1, L3.1, L4.1, Q1.3
LED_PWM: Q1.1, R5.1, U1.7
UPDI: J1.1, U1.6
VCC: BT1.1, C1.1, C2.1, J1.2, R1.1, R2.1, R3.1, R4.1, U1.1

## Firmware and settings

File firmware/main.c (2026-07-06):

#include <avr/io.h>
#include <avr/interrupt.h>
#include <avr/sleep.h>
#include <avr/eeprom.h>
#include <util/delay.h>

// LED brightness is a PWM duty cycle (0-255). Unlike v0.2, the LEDs have real
// series resistors, so the bright phase can run at full duty: peak current is
// set by R1-R4 by design, and steady drive at low current is both more
// efficient and flicker-free compared to chopping a higher peak.
#define LED_DUTY_MAX 255
// Subtle "glow" effect: breathe between LED_DUTY_MIN and LED_DUTY_MAX.
#define LED_DUTY_MIN 136
#define LED_GLOW_CYCLES 5
#define LED_GLOW_STEP_MS 5
#define LED_RAMP_STEP_MS 5
#define LED_FADE_STEP_MS 10

// Post-flash confirm: the flashing station writes FLASH_CONFIRM_ARMED to the
// first EEPROM byte as its final step, only after flash + fuses both verify.
// The first boot afterwards plays a distinct rapid blink -- so a hands-free
// station shows success on the board itself -- then clears the flag, so it
// fires exactly once per flash. A factory chip (0xFF) or an already-cleared
// one never blinks, and a flash that erased EEPROM (to 0xFF) but then failed
// before arming never reads as armed, so a confirm only ever means full success.
#define FLASH_CONFIRM_ADDR    ((uint8_t *)0)
#define FLASH_CONFIRM_ARMED   0xA5
#define FLASH_CONFIRM_CLEARED 0x00
#define FLASH_CONFIRM_BLINKS  4
#define FLASH_CONFIRM_MS      80

// A wake edge only counts as a press if the button still reads pressed this
// much later. Filters contact bounce on *release* (which can also produce
// falling edges) so lifting a glass off the coaster doesn't replay the show.
#define BUTTON_DEBOUNCE_MS 20

// Rapid full-brightness blink, visually distinct from the gentle multi-second
// breathe of show(), so it reads as "just programmed" across a workbench.
// Drives PA3 directly (no PWM) -- the LEDs run at the peak current set by
// R1-R4, which is fine for a sub-second confirm.
static void flash_confirm(void)
{
  for (uint8_t i = 0; i < FLASH_CONFIRM_BLINKS; i++)
  {
    PORTA.OUTSET = PIN3_bm;
    _delay_ms(FLASH_CONFIRM_MS);
    PORTA.OUTCLR = PIN3_bm;
    _delay_ms(FLASH_CONFIRM_MS);
  }
}

// Play the light show: ramp up, breathe LED_GLOW_CYCLES times ending on the
// dim phase (rising right before the fade would read as a restart), then a
// perceptually-even fade to black. Roughly 8 seconds end to end.
static void show(void)
{
  // TCA0 single-slope PWM on PA3 (WO0, default PORTMUX routing):
  // 3.33MHz / 16 / 256 ~= 814Hz, comfortably above flicker.
  TCA0.SINGLE.PER = 0xFF;
  TCA0.SINGLE.CMP0 = 0;
  TCA0.SINGLE.CTRLB = TCA_SINGLE_CMP0EN_bm | TCA_SINGLE_WGMODE_SINGLESLOPE_gc;
  TCA0.SINGLE.CTRLA = TCA_SINGLE_CLKSEL_DIV16_gc | TCA_SINGLE_ENABLE_bm;

  // Ramp up to full brightness.
  for (uint8_t duty = 0; duty < LED_DUTY_MAX; duty++)
  {
    TCA0.SINGLE.CMP0BUF = duty;
    _delay_ms(LED_RAMP_STEP_MS);
  }

  // Glow effect: breathe gently between max and min brightness.
  for (uint8_t cycle = 0; cycle < LED_GLOW_CYCLES; cycle++)
  {
    for (uint8_t duty = LED_DUTY_MAX; duty > LED_DUTY_MIN; duty--)
    {
      TCA0.SINGLE.CMP0BUF = duty;
      _delay_ms(LED_GLOW_STEP_MS);
    }
    if (cycle == LED_GLOW_CYCLES - 1)
      break;
    for (uint8_t duty = LED_DUTY_MIN; duty < LED_DUTY_MAX; duty++)
    {
      TCA0.SINGLE.CMP0BUF = duty;
      _delay_ms(LED_GLOW_STEP_MS);
    }
  }

  // Fade from the dim point to dark. Duty is linear in light output but
  // perception is logarithmic; squaring the ramp position spends most of the
  // time at the dim end, which reads as an even fade instead of a snap.
  for (uint8_t step = LED_DUTY_MIN; step > 0; step--)
  {
    TCA0.SINGLE.CMP0BUF = (uint8_t)(((uint16_t)step * step) / LED_DUTY_MIN);
    _delay_ms(LED_FADE_STEP_MS);
  }

  // PWM off, gate driven firmly low (R5 also holds it low whenever PA3
  // floats, e.g. during programming or reset).
  TCA0.SINGLE.CTRLA = 0;
  TCA0.SINGLE.CTRLB = 0;
  PORTA.OUTCLR = PIN3_bm;
}

// The button interrupt exists only to wake the CPU from power-down; waking
// returns control to the main loop right after sleep_cpu().
ISR(PORTA_PORT_vect)
{
  PORTA.INTFLAGS = PORT_INT6_bm;
}

int main(void)
{
  // Snapshot and clear the reset cause (cleared by writing 1s).
  uint8_t reset_flags = RSTCTRL.RSTFR;
  RSTCTRL.RSTFR = reset_flags;

  // Unused pins: pull-up so they don't float, input buffer off to save power.
  // PA0 is UPDI and PA3 is the PWM output; both are left alone here.
  PORTA.PIN1CTRL = PORT_PULLUPEN_bm | PORT_ISC_INPUT_DISABLE_gc;
  PORTA.PIN2CTRL = PORT_PULLUPEN_bm | PORT_ISC_INPUT_DISABLE_gc;
  PORTA.PIN7CTRL = PORT_PULLUPEN_bm | PORT_ISC_INPUT_DISABLE_gc;

  // Button on PA6: internal pull-up, interrupt on falling edge. PA6 is one of
  // the two fully-asynchronous pins (Px2/Px6), so the edge wakes the chip
  // from power-down with the main clock stopped.
  PORTA.PIN6CTRL = PORT_PULLUPEN_bm | PORT_ISC_FALLING_gc;

  // LED gate pin: output, low (LEDs off).
  PORTA.OUTCLR = PIN3_bm;
  PORTA.DIRSET = PIN3_bm;

  set_sleep_mode(SLEEP_MODE_PWR_DOWN);
  sei();

  // If the flashing station just armed the confirm flag, blink once to show
  // the board itself that programming succeeded, then clear it. This is a
  // UPDI-reset boot (not a power-on), so it never collides with the show below.
  if (eeprom_read_byte(FLASH_CONFIRM_ADDR) == FLASH_CONFIRM_ARMED)
  {
    flash_confirm();
    eeprom_write_byte(FLASH_CONFIRM_ADDR, FLASH_CONFIRM_CLEARED);
  }

  // Inserting the battery is a power-on reset: play one show as a built-in
  // self test. Any other reset cause -- in particular a brown-out, meaning a
  // dying cell sagged below 1.8V mid-show -- skips straight to sleep, so a
  // worn battery cannot sustain a reset-relight loop.
  if (reset_flags & RSTCTRL_PORF_bm)
    show();

  while (1)
  {
    // Discard any presses that arrived during the show, then sleep until the
    // next falling edge on the button. While a glass parks the button held
    // down, no further falling edges can occur, so the chip stays asleep.
    PORTA.INTFLAGS = PORT_INT6_bm;
    sleep_enable();
    sleep_cpu();
    sleep_disable();

    // Only a press that is still held after the debounce window plays the
    // show; edges from release bounce read as released here and fall through
    // back to sleep.
    _delay_ms(BUTTON_DEBOUNCE_MS);
    if (!(PORTA.IN & PIN6_bm))
      show();
  }

  return 0;
}

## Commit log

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2026-06-06 Fix reset-relight loop and add breathing glow effect
    A worn CR2032 sagging under LED load could brown out the MCU
    mid-show; since a reboot unconditionally replayed the show, the
    device got stuck relighting forever. Three layers of fixes:
    - Enable BOD at 1.8V awake (requires hfuse=0xFD) so low-voltage
    operation resets cleanly instead of executing undefined behavior,
    and disable it during sleep via BODCR (the BODS bits are not in
    MCUCR on the ATtiny13A) to keep standby at ~4uA.
    - Keep a magic cookie in .noinit SRAM to detect a show interrupted
    by a reset and go back to sleep instead of replaying. The show
    must play on any other state, including scrambled SRAM: a button
    press colla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
    [main.c]
2026-06-06 Make flashing reliable over a hand-held ISP cable
    Fix the install target (usbasp uses -P usb, no baud rate; drop -F)
    and tune it for this board's quirks: the LEDs hang on the MOSI line,
    so writes silently truncate at higher ISP clocks while reads stay
    reliable (data returns on the unloaded MISO line). Write at 32kHz
    without inline verification, then verify in a separate pass at
    16kHz. Add a fuses target for the one-time BOD setup and a reset
    target for a mildly wedged USBasp.
2026-06-06 Document hardware: design files, BOM, flashing, power estimates
    Add the design files (Protel netlist as the canonical machine-readable
    circuit description, schematic SVG for humans, EasyEDA source for
    editing) and rewrite the README: how the device works, flashing
    recipe with fuse settings and hard-won gotchas, BOM matching the SMD
    parts actually on the board (with verified sources and pricing),
    JLCPCB production cost estimates, power budget and battery life
    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
2026-06-07 Add v0.3 hardware design specification
    ATtiny402 with UPDI programming, button on a wake-capable GPIO
    instead of shorting the battery, per-LED series resistors behind a
    low-side MOSFET, proper decoupling, and a 3-pad programming header.
    Includes pin map, net-by-net connections, BOM with JLCPCB catalog
    tiers, ordering plan for 30 boards, firmware port checklist, and
    first-article validation list.
2026-06-08 Add v0.3 KiCad hardware design, generated and verified
    Reorganize the repo into three domain folders, each with a
    self-contained Makefile, plus a top-level Makefile that forwards to
    them (make install / board / review / clean):
    firmware/ AVR C firmware and its build/flash Makefile
    pcb/ v0.3 board design + generator + footprints
    enclosure/ 3D-printed shell (design constraints; CAD source TODO)
    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
    [coaster.kicad_pcb]
2026-06-09 Fix long-press brown-out and simplify show-on-press logic
    Two related fixes to the wake-and-play behavior, both rooted in the
    v0.2 button dead-shorting the battery to power-cycle the MCU:
    - Replace the .noinit SRAM cookie with the MCUSR PORF reset flag to
    decide whether to play the show. The cookie distinguished a button
    press from a mid-show brown-out by whether SRAM survived, which is
    timing-dependent and differed between short and long presses --
    leaking state across presses. PORF only cares that VCC reached ~0V,
    which every press does regardless of hold time, so short and long
    presses now run an identical path. Drops both .noinit bytes, the
    inverse byte, both helpers, the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
    [main.c]
2026-06-09 Make board regeneration deterministic
    Every KiCad board item gets a random UUID at construction and KiCad
    serializes items in UUID order, so each generate.py run rewrote every
    UUID and reshuffled the file -- a ~4000-line no-op diff on regeneration.
    Seed KiCad's UUID generator (pcbnew.KIID.SeedGenerator) with a fixed
    value before building; with the script's fixed build order this makes
    the UUID sequence, and thus the whole file, byte-stable across runs.
    The fill child process uses a distinct seed so its UUIDs can't collide
    with the board items written by the parent.
    coaster.kicad_pcb is rewritten once to the new seeded baseline (DRC: 0
    violations); regeneration is byte-identical from here on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
    [coaster.kicad_pcb]
2026-06-09 Switch battery to CR2016 (MY-2016-02) to slim the enclosure
    The battery holder was the tallest component, sitting just above the
    button. Swap the CR2032 holder (MY-2032-12, 3.6mm tall) for a CR2016
    holder (MY-2016-02, 2.2mm) -- 1.4mm lower. ~75mAh still gives 2+ years
    at a few presses a day, since µA sleep dominates and presses are ~free.
    New footprint land pattern is from the MY-2016-02 datasheet (WD-CP-0081):
    clip pads 5.6x1.75mm at 21.75mm center-to-center, 10mm center contact --
    distinct from the 2032's pattern, verified against both datasheets.
    The board file also re-baselines to generate.py's deterministic seeded
    UUID layout; the file committed in 8bfbe22 still carried the pre-seed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
    [coaster.kicad_pcb]
2026-06-11 Add v0.2.1 enclosure CAD source with STEP/STL export build
    The FreeCAD source of truth for the 3D-printed shell: Top (spiral
    flexure lid), Bottom (PCB tray), and Shield (thin insert between PCB
    and lid) bodies. export.py runs under freecadcmd to validate the
    document (full recompute, every body a valid closed solid) and export
    per-body STEP and STL files; the enclosure Makefile exposes the same
    build/test/clean verbs as firmware/ and pcb/, and the top-level
    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
    [coaster.FCStd]
2026-06-11 Make board and enclosure builds work on macOS
    KiCad and FreeCAD app bundles don't expose their CLIs on PATH, so the
    README now documents one-time symlinks for kicad-cli, freecadcmd, and
    kicad-python (KiCad's bundled interpreter, the one with the pcbnew
    bindings). The Makefiles call the commands by name; the only lookup
    left is the pcb build preferring kicad-python over python3, and
    generate.py resolving the stock footprint library path per platform.
2026-06-11 Regenerate board under KiCad 10
    No design change: design.py is untouched and the regenerated board
    passes connectivity validation and DRC. KiCad 10 rewrites the file in
    its new format, so this no-op migration is its own commit to keep real
    design diffs reviewable. KiCad 10 is now the reference version for
    regenerating the committed board.
    [coaster.kicad_pcb]
2026-06-11 Swap Q1 to AO3400A for logic-level gate drive
    The 2N7002's gate threshold is spec'd up to 2.5V worst-case, which a
    CR2016 spends most of its life barely above -- a high-threshold part
    plus a worn cell reads as dim or flickering LEDs. The AO3400A (LCSC
    C20917, JLCPCB basic catalog, same SOT-23 pinout and price) is fully
    enhanced at 2.5V with Vgs(th) of 0.65-1.45V.
    [coaster.kicad_pcb]
2026-06-11 Move battery-return vias out of the cell contact pad
    The CR2016 presses directly on BT1 pad 2 (bare copper, mask-defined),
    and the two GND stitching vias sat inside that 10mm contact circle --
    drill dimples and flux right at the contact surface risk an
    intermittent battery connection that presents as random resets. The
    vias now sit just outside the circle, fed by short spokes from the pad
    center.
    [coaster.kicad_pcb]
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2026-06-11 Document the shield as the liquid strategy
    The Shield body is a continuous clear-PETG membrane over the PCB:
    drips through the flexure's spiral cuts land on it and shed outward
    instead of reaching the electronics, the bare battery contact, or the
    switch. Record the planned center-post retention groove (the current
    snap-fit holds by hoop tension, which creep relaxes and every press
    flexes) and add a splash test to the first-article checklist.
2026-06-11 Add LED brightness validation to the first-article checklist
    v0.2 brightness was set by battery sag; v0.3's is set by R1-R4, so the
    two won't match by construction. 150R is a starting value to verify
    through an actual glass, with 100R as the rework fallback.
2026-06-11 Upgrade LEDs to XL-1608UWC-04 for ~3x brightness at the same current
    Same 0603 footprint and 120 degree viewing angle as the KT-0603W, but
    400 min / 630 typ mcd at 20mA versus 173-207. Cool white, Vf 2.6-2.8V
    typical, LCSC C965808 (JLCPCB extended: one more $3 feeder fee, or
    $0.10/board at qty 30). Also note white soldermask in the ordering
    plan -- the board face is the reflector behind the LEDs under the
    clear shield.
    [coaster.kicad_pcb]
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2026-06-11 Swap U1 to the ATtiny202 to cut the dominant BOM cost
    Same SOIC-8 pinout, peripherals, sleep current, and firmware as the
    ATtiny402 -- only flash/SRAM shrink (2KB/128B, still 7x the current
    firmware) -- for $0.43 vs $0.65 (LCSC C2052951). The 402 stays a
    drop-in substitute at order time: a binary built for the 202 runs on
    it unmodified.
    [coaster.kicad_pcb]
2026-06-11 Port firmware to the ATtiny202
    The v0.2 firmware existed to work around the v0.2 board: PWM as the
    only LED current limit, PORF forensics to tell presses from brown-outs,
    and a settle phase to let the cell recover from the wake dead-short.
    The v0.3 board removes the causes, so the port is mostly deletion:
    - Wake: PA6 falling-edge interrupt from power-down (fully-async pin);
    a 20ms debounce also filters release-bounce edges so lifting a glass
    off a held button does not replay the show.
    - PWM: TCA0 single-slope on PA3/WO0 at ~814Hz, duty via CMP0BUF. The
    bright phase runs at full duty since R1-R4 set the current; same
    show choreography (ramp, breathe x5 to the dim point, squared fade)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
    [main.c]
2026-06-11 Rewrite README for v0.3
    The BOM, power table, flashing recipe, and how-it-works narrative all
    described the v0.2 board (ATtiny13A, CR2032, dead-short wake, usbasp
    gotchas), which is archived at release v0.2.1. Describe v0.3 instead:
    GPIO wake with the brown-out fail-dark logic, UPDI flashing over a
    USB-serial adapter, updated cost and battery-life estimates, and a
    pointer to pcb/DESIGN.md for the BOM instead of a second copy that
    would drift. Drop the make reset forward (the wedged-USBasp recovery
    died with the ISP header).
2026-06-11 Add economies-of-scale table to the production estimates
    Per-unit cost at qty 30 / 100 / 1k / 10k, separating the lines that
    amortize (fees, fixed costs, battery, enclosure process) from the ones
    that don't (parts). The same design lands at ~$3.40 in a hobby batch,
    ~$2.25 at 1k with a small FDM print farm (no tooling commitment, with
    rapid aluminum tooling as the alternative when 1k is a milestone
    toward 10k), and ~$1.10 at 10k with a molded shell -- the gap is
    volume and process, not BOM.
2026-06-11 Model the battery holder's true body and re-place it with real clearances
    The MY-2016-02 footprint encoded only its copper: two clip pads and
    the contact circle. The physical part is a 22.8x15.2mm chamfered frame
    2.2mm tall, and the bare CR2016 overhangs it on both depth sides --
    none of which was drawn on any layer, in the courtyard, or in a 3D
    model, so DRC and the STEP fit-check were blind to it. Verified the
    pad geometry against datasheet WD-CP-0081 (exact match, and ~1mm
    tighter than the proven v0.2 CR2032 holder), then:
    - Footprint: true frame + feet + cell outline on F.Fab, courtyard as
    the real envelope polygon, insertion mouth marked, and a generated
    STEP body (frame + cell) so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
    [coaster.kicad_pcb]
2026-06-12 Automate the JLCPCB bundle and run the toolchain in pinned containers
    Two related changes that make the board orderable and the whole build
    reproducible off any host.
    Order automation:
    - pcb/fab.py + `make fab` emit the three JLCPCB uploads (Gerbers zip, BOM,
    CPL) from the board geometry and design.py's part data.
    - design.py gains the LCSC numbers, assembly exclusions (J1 header, mounting
    holes), and a rotation-correction hook as the single source of truth; the
    four previously-"any basic" passives are pinned to in-stock Basic SKUs.
    Pinned toolchain containers (tools/), each base-pinned by digest:
    - coaster-pcb: KiCad 10.0.2. The committed board is KiCad-10 format and host
    KiCad dr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
    [coaster.kicad_pcb]
2026-06-14 Add a calibrated axisymmetric press simulation for the donut-piston Top
    Slices the FreeCAD solid through its axis, meshes the meridian (Gmsh, CAX6),
    and solves the press in CalculiX — the geometry is read from the model, never
    reconstructed, so the simulation cannot drift from the CAD. Calibrated from one
    measured click force and cross-validated against a second press at a different
    radius; emits a click-force-vs-load-radius curve plus a validation table.
    Runs via `make sim` in the pinned FreeCAD container (gmsh and ccx ship in the
    AppImage). Brings the donut-piston design (coaster-v0.2.2.FCStd) into the tree
    alongside the v0.2 spiral enclosure, which remains the canonical build.
    [coaster-v0.2.2.FCStd]
2026-06-16 Swap LEDs to KT-0603W and drop LED resistors to 100Ω
    The v0.3 board specified XL-1608UWC-04 LEDs (C965808) on the stated
    rationale that they were ~3x brighter than the basic KT-0603W. The
    datasheet says otherwise: XL-1608UWC-04 is 130mcd@20mA, KT-0603W is
    360mcd@5mA. At the few mA a CR2016 drives through these LEDs, the
    KT-0603W is ~11x brighter at the operating point — and it's a Basic
    part, so no feeder fee. Drop R1-R4 150Ω→100Ω to push a little more
    current now that LED efficiency, not the resistor, sets the brightness.
    BOM/CPL change only; gerbers and drill stay content-identical to
    v0.3.0-rc1 (component value fields don't reach the silkscreen). DRC clean.
    [coaster.kicad_pcb]
2026-06-16 Sync enclosure to the v0.3 donut-piston Top (drop the shield)
    The committed enclosure was still the v0.2.1 spiral-flexure design — three
    bodies including a clear-PETG Shield. The v0.3 enclosure (authored in Drive as
    Coaster v0.2.2.FCStd) is a solid donut-piston: the top is a continuous skin
    that deflects as a whole, on a ring of snap arms, with no spiral cuts. Verified
    the Top is built entirely from additive pads (zero pockets/cuts) and its top
    face is a full continuous disc — so there is no open liquid path, and the
    separate shield membrane is no longer needed.
    - coaster.FCStd: v0.2.1 spiral flexure -> v0.3 donut-piston (Top + Bottom)
    - export.py: drop the Shield body
    - sim: DESIGN_FIL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
    [coaster.FCStd]
2026-06-26 Thin the v0.3 enclosure 1mm and rework the snap arms
    - BottomHeight 7.5->6.5mm (8.1mm assembled); press post shortened
    4.5->3.5mm so the post tip stays on the button
    - Snap arms: outer root fillet 0.4->0.8mm and flexing beam thinned
    1.75->1.0mm to cut root bending strain
    - Snap pockets tightened to 0.1mm tangential clearance (was 0.2)
    - sim: meridian arm-detection made geometry-relative so it tracks a
    re-dimensioned lid instead of a hard-coded height
    - README: stack-up, snap arms as a known weak point, and the fit knobs
    Interim checkpoint before replacing the cantilever snaps with a bayonet.
    [coaster.FCStd]
2026-06-26 Thicken the snap-arm beam to 1.6 mm
    Back off the bayonet (a flush thin lid is too hard to grip to twist) and
    return to the cantilever snaps, thickened from 1.0 to 1.6 mm to test whether
    the thin arms were failing on poor print quality / weak layer bonding rather
    than bulk bending strain. 1.6 mm is the cap with the 0.8 mm root fillets
    intact; thicker needs the hook moved off mid-beam. Top body only.
    [coaster.FCStd]
2026-06-30 Add an anti-stick groove web to the donut-piston Top
    A sweating glass capillary-bonds to the smooth lid and lifts the lightweight
    coaster when raised. Vent the film with a polar groove web on the glass face
    (0.4 mm deep x 1.4 mm wide): 6 concentric rings + a rim ring break the contact
    into ~2 mm bands, and 24 radial spokes carry venting out to the rim, so it works
    for any glass-base size.
    Grooves are blind (>=1.2 mm skin in the disc), so the waterproof barrier holds.
    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
    [coaster.FCStd]
2026-07-01 Switch the anti-stick web to a uniform crosshatch grid
    Replace the radial spider-web (busy on a circular face) with a uniform 4 mm
    crosshatch that reads as a calm texture. It runs edge to edge -- breaking contact
    into ~2.6 mm patches and venting to the rim for any glass-base size -- by crossing
    the outer flexure hinge over the continuous 0.6 mm backing ring: as a solid plate
    it face-supports the criss-cross so the thin membrane isn't islanded (a discrete
    per-groove bump meets the tiles only at edges and would fall off), the grid tapers
    to a 0.2 mm notch across it leaving >=0.4 mm skin, and it keeps the click ~10%
    firmer. Grooves stay blind (>=1.2 mm skin in the disc); the center is left clea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
    [coaster.FCStd]
2026-07-01 Rework the anti-stick pattern as circular bumps in concentric rings
    The square grid read as square bumps and sat off-centre on the round lid (a
    lattice cut awkwardly by the round centre keep-out). Replace it with an array of
    Ø4 mm circular bumps (0.4 mm proud) laid out in concentric rings -- rotationally
    symmetric about the centre, round bumps, round centre, all concentric. The
    0.4 mm-recessed field between them is one connected vented network to the rim;
    bumps never touch, so nothing closes into a suction pocket.
    Built by recessing the field in radial bands (0.4 mm in the thick bands, 0.2 mm
    across the outer hinge over the continuous 0.6 mm backing ring) then padding the
    round bumps back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
    [coaster.FCStd]
2026-07-01 Add a continuous raised outer ring to the bump lid for printing
    The recessed field ran to the disc edge, leaving the rim with no continuous
    first-layer perimeter (the face-down print had nothing to lay an edge against,
    so it printed ragged). Leave the outer ~3 mm (r 42-45) at full glass-face height
    as a solid raised ring, recessing the bump field only to r42. It doesn't affect
    venting -- air enters at the glass base edge over the field, not at the coaster
    rim, and the ring sits beyond any real glass base. Barrier and click unchanged.
    [coaster.FCStd]
2026-07-01 Reset the lid to flat v0.3 and add radial drainage ridges as v0.3.1
    A printed test of the recessed circular-bump lid suction-cupped: a shallow
    recessed field floods with sweat and bridges into one sealed film. The fix is
    drainage, not contact-area reduction. Drop the anti-stick experiments back to a
    plain flat Top, kept as coaster-v0.3.FCStd, and make coaster.FCStd the v0.3.1
    texture: 24 radial channels (1.0 mm wide x 0.4 mm deep) from r13 out to the rim
    that drain sweat off the edge and vent air in, instead of trapping it.
    Channels are blind (>=1.2 mm skin in the disc, full-thickness plateaus between).
    They cross the 0.4 mm outer flexure hinge over a continuous 0.6 mm underside
    backing rin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
    [coaster-v0.3.FCStd, coaster.FCStd]
2026-07-01 Reinforce the tray floor to 1.2 mm under the board
    The bare 0.5 mm tray floor dimpled through to the underside when the board was
    pressed onto the pegs. Pad a central Ø52 disc up to 1.2 mm (bending stiffness ~14x
    higher). It grows into the dead space below the board -- which seats on the 2 mm
    corner ledge at z~2.0 -- so overall height, the board seat, and lid clearance are
    unchanged, leaving ~0.8 mm under the board.
    [coaster.FCStd]
2026-07-01 Deepen the floor reinforcement to 1.8 mm (board underside is flat)
    The board's underside is completely flat, so back it almost fully: raise the
    central floor disc to 1.8 mm, stopping 0.2 mm below the board seat. ~45x stiffer
    than the original 0.5 mm and the flat board now bottoms on a stiff floor almost
    immediately, so it physically can't dimple. The corner ledge still sets the seat
    height; height and lid clearance unchanged.
    [coaster.FCStd]
2026-07-01 Rework v0.3.1 ridges: fewer, wider, deeper, stop short of the rim
    First print of the 24 thin 1.0 x 0.4 mm radial lines was bad: too small to feel,
    fused together, and running to the very rim printed jagged. Redo as 12 channels
    2.5 mm wide x 0.8 mm deep, ending at r42 (~3 mm flat rim for a clean print edge).
    They still cross the outer hinge on the 0.6 mm backing ring, tapering to a 0.2 mm
    notch there (>=0.4 mm skin). Deep thick-band spans keep >=0.8 mm skin. Bottom
    floor reinforcement unchanged.
    [coaster.FCStd]
2026-07-02 Make the channels uniform-depth; back the hinge from the underside
    The tapered hinge crossing left an ugly depth step near the rim. Cut the channel
    at a uniform 0.8 mm the whole way and instead add material on the *underside*
    under each channel at the hinge -- 12 discrete backing bars (3.5 mm x 1.2 mm) so
    0.4 mm skin remains under the 0.8 mm groove. Radial channels don't island the
    membrane and the hinge still flexes between them, so the click stays near the
    flat lid's (dropped the continuous backing ring / +10%).
    [coaster.FCStd]
2026-07-02 Revert the bogus tray-floor disc (it filled the board's seat)
    The 1.8 mm floor disc was a misdiagnosis: the board sits flat *on* the 0.5 mm
    indent floor, not hovering above it, so the disc grew straight into the board's
    seat -- a bogus raised disk where the board drops in. Remove it; floor is back to
    the original 0.5 mm. Reinforcing it properly is a separate change (it costs height,
    since there's no room above or below the seat).
    [coaster.FCStd]
2026-07-02 Bump the tray floor to 0.6 mm (3 print layers) via a shallower recess
    Instead of the reverted disc, make the PCB Recess pocket 0.1 mm shallower
    (1.5 -> 1.4 mm) so the whole board-seat floor rises uniformly from 0.5 to 0.6 mm
    -- three full print layers instead of an awkward 2.5. Board seat rises 0.1 mm
    (negligible for post travel); overall height unchanged. The board sits flat on
    this floor, so a bigger reinforcement would cost height or lid clearance.
    [coaster.FCStd]
2026-07-03 Chamfer the channel walls 45 deg for cleaner face-down printing
    The square channel profile left a flat, down-facing 2.5 mm floor that bridged
    and printed rough (the Top prints face-down, so each channel is a recess in the
    bed-side surface). Add a -45 deg TaperAngle to the channel pocket: the channel is
    now wide at the glass face, narrowing to a ~1.1 mm floor, so the walls are
    self-supporting overhangs and the bridged span shrinks. Also drains better (no
    square corners). Depth (0.8 mm) and hinge backing/skin unchanged; press unchanged.
    [coaster.FCStd]
2026-07-03 Narrow channels to 2.0 mm at ~40 deg to shrink the bridged floor
    The 45 deg chamfer on the 2.5 mm channel still left a ~1.1 mm flat, down-facing
    floor that bridges. Middle ground: narrow to 2.0 mm and taper ~40 deg (just under
    45, still self-supporting) -> ~0.8 mm floor, wide/feelable channel kept. A full V
    (no floor) would need <=1.6 mm at this depth. Depth 0.8 mm, hinge backing/skin,
    and press all unchanged.
    [coaster.FCStd]
2026-07-05 Shorten the tray 0.5 mm (BottomHeight 6.5 -> 6.0)
    Drop the tray height knob 0.5 mm; the lid placement, snap pockets and rim track
    it, so the whole interlock lowers and assembled height goes 8.1 -> 7.6 mm. Leave
    the press post at 3.5 mm (don't re-lengthen it) -- spend ~0.5 mm of assembly play
    instead, per the request. Print-test: confirm the lid still seats (battery-holder
    clearance tightens by 0.5 mm) and the button feel; raise BottomHeight toward
    6.2-6.5 if it binds.
    [coaster.FCStd]
2026-07-05 Revert "Shorten the tray 0.5 mm (BottomHeight 6.5 -> 6.0)"
    This reverts commit c3929af3892cbb0aeb238b36e3c4f81bce1d080e.
    [coaster.FCStd]
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
